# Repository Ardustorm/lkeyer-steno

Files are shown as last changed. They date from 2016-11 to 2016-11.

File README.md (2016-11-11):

LKeyer is my attempt at designing a simple Steno machine that is cheap and easy to make. The code is written by [CharleyShattuck](https://github.com/CharleyShattuck/Steno-Keyboard-Arduino). This is still a work in progress. Eventually I would love to replace the arduino with a raspberry pi zero and create a standalone steno machine, but one step at a time.

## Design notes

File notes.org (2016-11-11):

#+STARTUP: indent
#+STARTUP: hidestar

* Where I am so far
[2016-11-11 Fri]
The current design mostly works but there are a few things that need improvement. The aluminum foil I used as the ground plane is ripping in a few places from the wires hitting it. Also, some of the keys are weaker than others because of how I routed the wires. Here is what I will try to fix/improve in the next version:

** Thicker hinges
I often mis-stroked because they keys were too easy to activate (though part of the problem was that the wires pulled some of the keys down more). I am thickening the hinges so that I don't mess up as much as I am learning. This might be something that I reduce as I become more proficient.

** Better routing of wires
Some of the wires are pulling the keys down. I am going to try and add a hole or path along the key so that the wires do not move the keys. I am also going to try and add a channel in the frame so that the wires are hidden more.

** Better base
Instead of aluminum foil I am going to use a piece of thin sheet metal. (This could be part of a soda can.) That way the wires cannot rip a hole in it.

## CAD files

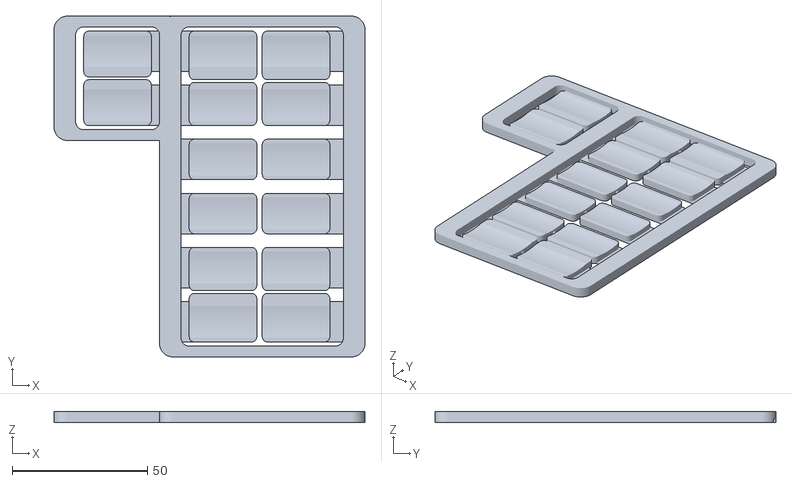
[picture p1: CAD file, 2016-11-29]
STLs/lkeyerSteno.stl
115.0 x 126.0 x 4.00

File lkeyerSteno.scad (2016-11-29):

use <MCAD/shapes.scad>;

$fn = 100;


//print bed (sort of)
//color([.9,.6,.6])translate([-20,0,0])cube([120,130,.3],center=true);
hingeThickness = .35;


/////////// Print this \\\\\\\\\\\\

difference() {
   union() {
      keyBankWidth([3,-1,0,0,1,-3]);
      translate([-53.5,40,0]) rotate([0,0,0]) color([.8,.8,.8,.9]) keyBankWidth( [2,-2], single=true );
      // to keep ends from lifting
      translate([-34,62.75,0.1]) cube([10,.5,.2],center = true);
      translate([33,61.75,0.1]) cube([6,.5,.2],center = true);
   }
   translate([-34,20,0]) rotate([90,0,0]) cylinder(r= 2, h = 20,center = true);
}

//This module allows the construction of a board using an array to indicate which keys to add extra width to
module keyBankWidth(keys=[0,0,0,0,0,0], sideSpacing=20, frontSpacing=2, single=false) {
   frameThickness = 4;  //how tall the frame is
   frameWidth = 8;      //how wide the frame is in x and y
   hingeLength = 4;     //how long each hinge should be
   frameX1 = 25 + frontSpacing+hingeLength; //x value
   frameX = single ? frameX1 : frameX1 + 25 + hingeLength; //xval based on if two or 1 key
   frameY = sideSpacing*(len(keys) -.1);
   keyWidth = 15;
   keyLength = 25;


   
   difference() {
      union(){
					
	 //Key bank  -- Generate each key
	 translate([0,-(len(keys)-1)*sideSpacing/2  ,0])
	    for( i =[ 0 : len(keys)-1 ] ) {
	       //bottom set (+x)
	       xOffset = single ? -keyLength/2 : 0;
	       translate([xOffset,i*sideSpacing,0])
		  key(rounded=false,length=keyLength, keyWidth,rounding=2,thickness=3, hinge=hingeThickness,
		      extraWidth=keys[i]);
	       //top set (-x)
	       translate([-frontSpacing,i*sideSpacing,0]) rotate([0,0,180]) {
		  if( ! single ) {
		     key(rounded=false,length=keyLength, keyWidth,
			 rounding=2, thickness=3, hinge=hingeThickness, extraWidth=-keys[i]);
		  }
	       }

	    }

	 // frame
	 difference(){
	    //outside
	    translate([0,0,frameThickness/2]) roundedBox(frameX+2*frameWidth,frameY+2*frameWidth/2,frameThickness,5);
	    //inside
	    roundedBox(frameX,frameY,frameThickness+10,3);
		
	 }
      }

      // wire channel
      //Bottom channel
      translate([frameX/2 + frameWidth/2,frameWidth/2,0])
	 rotate([90,0,0]) cylinder(r=2,h=frameY+frameWidth,center=true);
      //Topchannel
      translate([-(frameX/2 + frameWidth/2),frameWidth/2,0])
	 rotate([90,0,0]) {
	 if( ! single ) {
	    cylinder(r=2,h=frameY+frameWidth,center=true);
	 }
      }
   
   }
}


module halfBoard(){
   union(){
      keyFrame();
      translate([46.2,-31.,0]) rotate([0,0,90])keyFrame(numOfKeys=1);
      translate([35,-63.5,1.5]) cube([25,5,3],center=true);
   }
}


module keyFrame(numOfKeys = 6, sideSpacing = 20, frontSpacing = 2, single=false){
   frameThickness = 4;  //how tall the frame is
   frameWidth = 8;      //how wide the frame is in x and y
   hingeLength = 4;     //how long each hinge should be
   frameX = 25*2+frontSpacing+hingeLength*2;
   frameY = sideSpacing*(numOfKeys+.1);
   union(){
      difference(){
	 translate([0,0,frameThickness/2])roundedBox(frameX+2*frameWidth,frameY+2*frameWidth,frameThickness,5);
	 roundedBox(frameX,frameY,frameThickness+10,3);
          
      }
      //the two banks of keys, facing each other
      translate([frontSpacing/2,0,0])keyBank(numOfKeys,sideSpacing);
      translate([-frontSpacing/2,0,0])mirror([1,0,0])keyBank(numOfKeys,sideSpacing);
   }
}

module keyBank(number=6, spacing = 20){
   /*Generates a set of keys with specified spacing*/
   translate([0,-(number*spacing)/2 +spacing/2 ,0])
      for(i= [0:spacing:(number-1)*spacing])
      {
	 translate([0,i,0]) key();
      }
}


module key(rounded=false,length=25, keyWidth=15,rounding=2,thickness=3, hinge=.4,extraWidth=0){
   /*generates a single key
     length is the vertical distance of the key
     keyWidth is the horizontal length of the key
     rounded true if key should be rounded
     rounding radius of curve
     thickness how thick the top part of the key should be
     hinge the thickness of the hinge, set to 0 to disable
     extraWidth makes keyWider negative numbers changes the side its on*/
   dishRadius = 35; //how big of a cylinder is used to create curve
   depthOfDish = 2.5; //how deep the resulting curve should be
   radiusOfWire = .7; //radius for the holes that have bare copper wire
   radiusOfInsulation = 1.2;//radius for the parts that have insulation still
   lengthOfHinge = 5.1;
   wireAttachment = 2; // how wire is attached to end of key 1:wrap, 2:hole&glue
   depthOfHole = 3; // how deep the hole is when wireAttachment=2
   difference() {
      //'base' part of the key
      union() {
	 translate([length/2,extraWidth/2,thickness/2])roundedBox(length,keyWidth+abs(extraWidth),thickness,rounding);
	 //Hinge
	 if(hinge > 0) {
	    translate([(length+5)/2+lengthOfHinge,0,hinge/2])cube([length-5,keyWidth,hinge],center=true);
          
	 }
      }


     
      //dishing
      translate([-1,0,dishRadius+depthOfDish])rotate([0,90,0])cylinder(r = dishRadius, h = length + 5,$fn=400);


      if(wireAttachment == 1) { //hole and wraping around end
	 //holes for the wire
	 union(){
	    //front groove
	    translate([-.5,0,-1])rotate([0,10,0])cylinder(r=radiusOfWire,h=thickness+2);
	    //Top groove
	    translate([0,0,thickness-radiusOfWire])rotate([0,90,0])cylinder(r=radiusOfWire,h=thickness+2);
	    //center hole
	    translate([length*.2,0,-1])rotate([0,0,0])cylinder(r=radiusOfWire,h=thickness+2);
	 }
      }
      else if( wireAttachment == 2 ) {
	 union() {
	    //center hole
	    translate([-.001,0,radiusOfWire+hingeThickness])rotate([0,90,0])cylinder(r=radiusOfWire,h=thickness+2);
	    //front groove
	    //translate([-.5,0,0])rotate([0,10,0])cylinder(r=radiusOfWire,h=radiusOfWire+hingeThickness);
	    //Bottom groove
	    //translate([length*.2,0,-radiusOfWire/2])r otate([0,90,0]) cylinder(r=radiusOfWire,h=length+lengthOfHinge/2);
	 }

      }



   }
}

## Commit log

2016-11-11 Working version
    [lkeyerSteno.scad]
2016-11-12 Adds variable width keys, additional ways of attaching wire
    [lkeyerSteno.scad, lkeyerSteno.stl, stenoVowels0V1.stl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]
2016-11-12 reduced size to save time and to fit print bed
    [lkeyerSteno.stl]
2016-11-12 adds thicker hinges, better wire routing
    [lkeyerSteno.scad, lkeyerSteno.stl, stenoVowels0V1.stl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]
2016-11-28 adds ability to generate only 1 side of a pair of keys, used for the thumb keys
    [lkeyerSteno.scad, lkeyerSteno.stl]
2016-11-29 reduce hinge thickness
    [lkeyerSteno.scad, lkeyerSteno.stl]
